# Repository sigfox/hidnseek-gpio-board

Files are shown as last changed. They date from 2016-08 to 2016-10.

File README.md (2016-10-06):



## SIGFOX GPIO Extension Board for the HidnSeek

This repo contains the .brd and .sch files required for the HidnSeek GPIO Extension Board. The design utilises a PCF8574N to breakout the I2C pins and allow for 8 additional digital I/O pins. The board also contains a reset button to place the device into DFU mode for re-flashing.

The intention of this board is to allow developers and makers to utilise the underlying hardware and to expand it with their own designs.

This board should be used in conjunction with the SIGFOX HidnSeek Dev Libraries as the I2C GPIO is driven by the wire.h library with a specific memory address (0x20). 

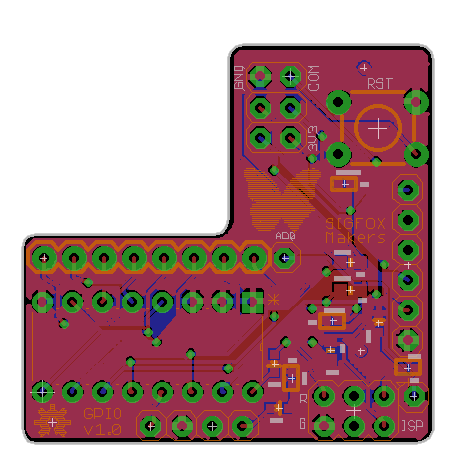
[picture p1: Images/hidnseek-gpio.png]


See https://github.com/hidnseek/hidnseek for more info about the HidnSeek.

Credit to **Stephane Driussi** for the daughter board pin layout

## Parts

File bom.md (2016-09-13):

| Component | Value | Part No. | Quantity |
|---|---|---|---|
| Capacitor | 100 nF | | 2 |
| Resistor  | 100 ohm | | |
| | 2.2 Kohm | | |
| | 470 ohm | | |
| LED | | | |
| IC | I/O Expander | PCF8574N | 1 |
| Button | | | |

To be completed...

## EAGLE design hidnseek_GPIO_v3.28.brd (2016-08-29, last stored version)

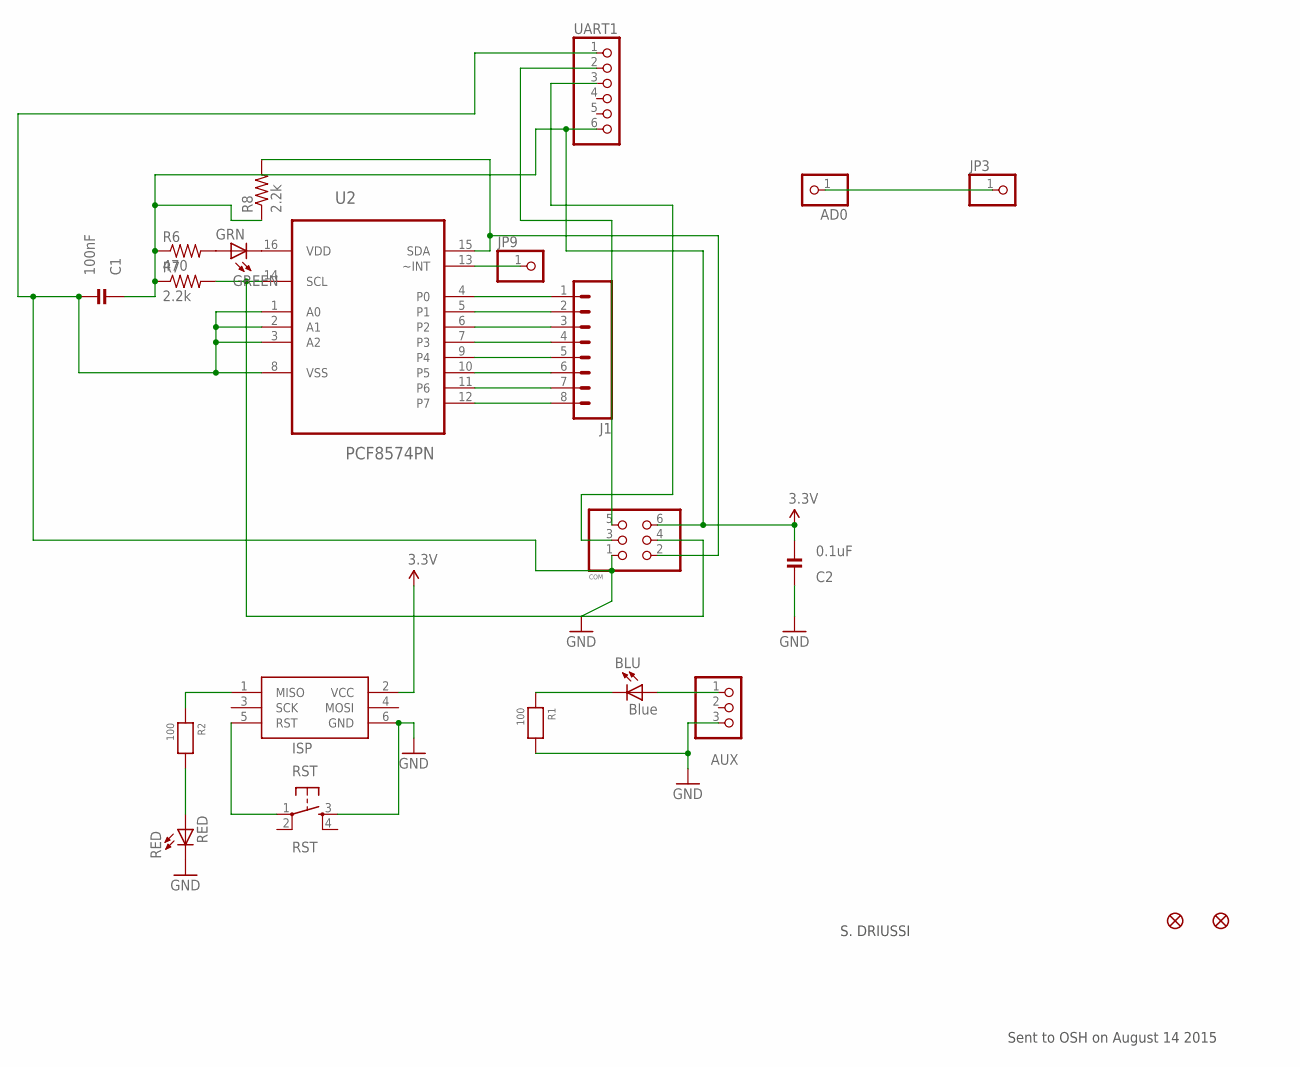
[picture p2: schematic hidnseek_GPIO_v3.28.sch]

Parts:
AD0: PINHD-1X1; 1X01
AUX: PINHD-1X3; 1X03
BLU: Blue; LED-0603; MOUSER# 604-APT1608SURCK
C1: 100nF; _0402; MOUSER# 81-GRM155R71C104KA88
C2: 0.1uF; _0402; MOUSER# 81-GRM155R71C104KA88
COM: PH_2X03HEADER_PTH; HEADER_02X03_PTH
GREEN: GRN; LED-0603; MOUSER# 604-APT1608SURCK
ISP: AVRISP-6; AVRISP
J1: M08; 1X08_ROUND
JP1, JP2: FIDUCIAL1X2.5; FIDUCIAL-1X2.5
JP3, JP9: PINHD-1X1; 1X01
R1, R2: 100; _0402; MOUSER# 660-RK73B1ETTP101J
R6: 470; 0603-RES
R7, R8: 2.2k; 0603-RES
RED: RED; LED-0603; MOUSER# 604-APT1608SURCK
RST: RST; TACTILE-PTH
U2: PCF8574PN; DIP254P762X420-16
UART1: PINHD-1X6; 1X06

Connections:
3.3V: C1.2, C2.1, COM.6, ISP.2 (VCC), R6.1, R7.1, R8.1, UART1.6
GND: AUX.3, C1.1, C2.2, COM.1, ISP.6 (GND), R1.2, RED.C, RST.3, U2.1 (A0), U2.2 (A1), U2.3 (A2), U2.8 (VSS), UART1.1
unnamed: BLU.C, R1.1
unnamed: AUX.1, BLU.A
unnamed: R2.2, RED.A
unnamed: ISP.1 (MISO), R2.1
unnamed: ISP.5 (RST), RST.1
unnamed: COM.3, UART1.3
unnamed: GREEN.C, U2.16 (VDD)
unnamed: GREEN.A, R6.2
unnamed: AD0.1, JP3.1
unnamed: COM.5, UART1.2
unnamed: COM.4, R7.2, U2.14 (SCL)
unnamed: COM.2, R8.2, U2.15 (SDA)
unnamed: J1.1, U2.4 (P0)
unnamed: J1.2, U2.5 (P1)
unnamed: J1.3, U2.6 (P2)
unnamed: J1.4, U2.7 (P3)
unnamed: J1.5, U2.9 (P4)
unnamed: J1.6, U2.10 (P5)
unnamed: J1.7, U2.11 (P6)
unnamed: J1.8, U2.12 (P7)
unnamed: JP9.1, U2.13 (~INT)

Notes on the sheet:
S. DRIUSSI
Sent to OSH on August 14 2015

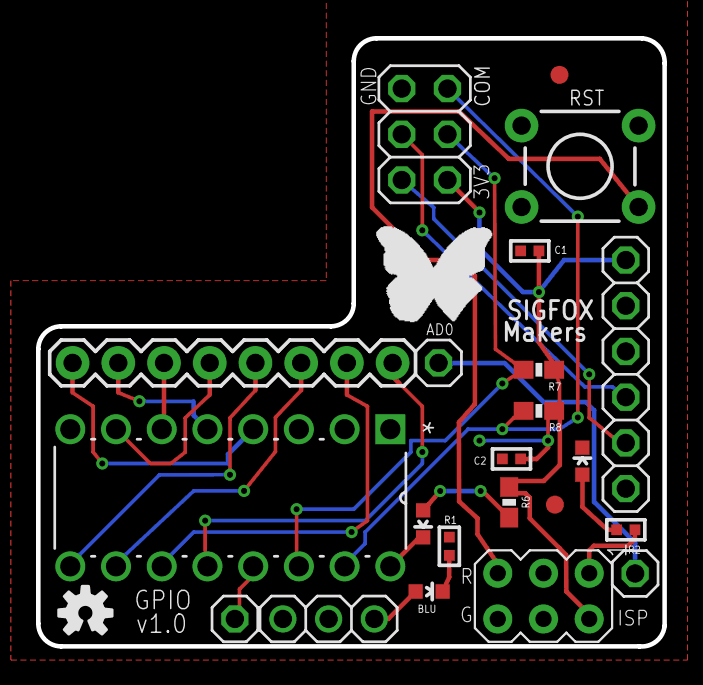
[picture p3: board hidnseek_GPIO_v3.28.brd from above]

Board: 2 copper layers, 34.8 x 33.8 mm, 23 parts (0 on the bottom side), 23 nets.

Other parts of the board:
U$3: OSHW-LOGOS; OSHW-LOGO-S

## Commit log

2016-08-29 Added .brd and .sch files to repo
    [hidnseek_GPIO_v3.28.brd, hidnseek_GPIO_v3.28.sch]
2016-08-29 fixed image of board
2016-08-29 Changed board size
2016-08-29 Increased trace width for 3.3 V

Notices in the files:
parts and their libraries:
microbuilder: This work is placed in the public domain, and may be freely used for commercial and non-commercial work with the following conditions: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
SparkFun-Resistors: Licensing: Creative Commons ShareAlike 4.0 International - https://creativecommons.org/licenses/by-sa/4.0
